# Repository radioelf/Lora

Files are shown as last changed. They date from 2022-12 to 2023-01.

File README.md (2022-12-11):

# Lora
Lora Radio
Molule E220 https://www.ebyte.com/en/product-view-news.html?id=1207

    Creative Commons License Disclaimer

  UNLESS OTHERWISE MUTUALLY AGREED TO BY THE PARTIES
  AND MAKES NO REPRESENTATIONS OR WARRANTIES OF ANY
  STATUTORY OR OTHERWISE, INCLUDING, WITHOUT LIMITAT
  FITNESS FOR A PARTICULAR PURPOSE, NONINFRINGEMENT,
  ACCURACY, OR THE PRESENCE OF ABSENCE OF ERRORS, WH
  DO NOT ALLOW THE EXCLUSION OF IMPLIED WARRANTIES,
  EXCEPT TO THE EXTENT REQUIRED BY APPLICABLE LAW, I
  ON ANY LEGAL THEORY FOR ANY SPECIAL, INCIDENTAL, C
  ARISING OUT OF THIS LICENSE OR THE USE OF THE WORK
  POSSIBILITY OF SUCH DAMAGES.

  http://creativecommons.org/licenses/by-sa/3.0/

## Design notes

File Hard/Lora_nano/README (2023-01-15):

PCB for Arduino Nano and module E220
Application: KiCad x86_64 on x86_64

Version: 7.0.0-rc1-unknown-00d77f624a~164~ubuntu22.04.1, release build

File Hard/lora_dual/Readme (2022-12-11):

Dual PCB for E220 PIC12F675 and ESP12F 
Application: KiCad

Version: 6.99.0-unknown-492e6548ff~162~ubuntu22.04.1, release build

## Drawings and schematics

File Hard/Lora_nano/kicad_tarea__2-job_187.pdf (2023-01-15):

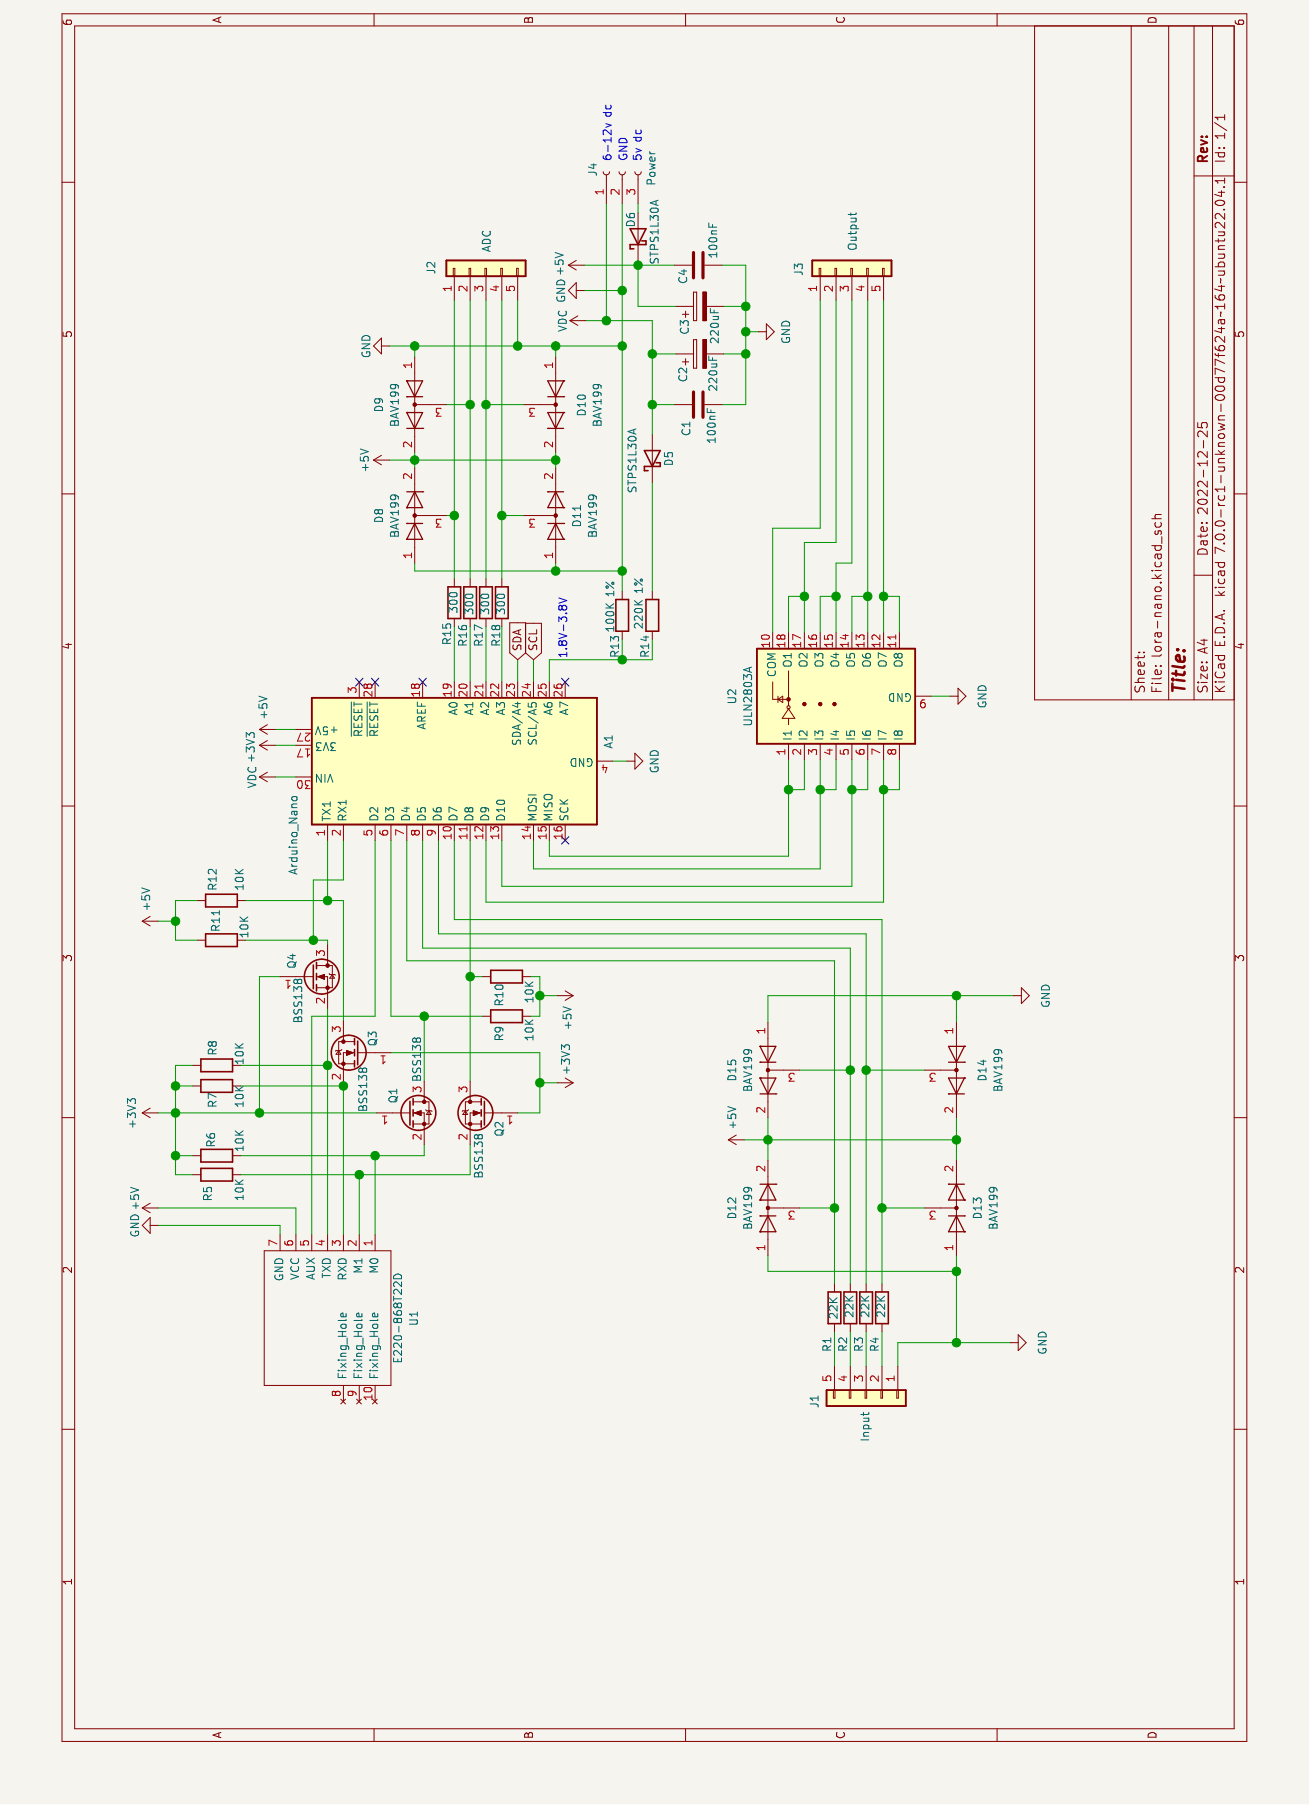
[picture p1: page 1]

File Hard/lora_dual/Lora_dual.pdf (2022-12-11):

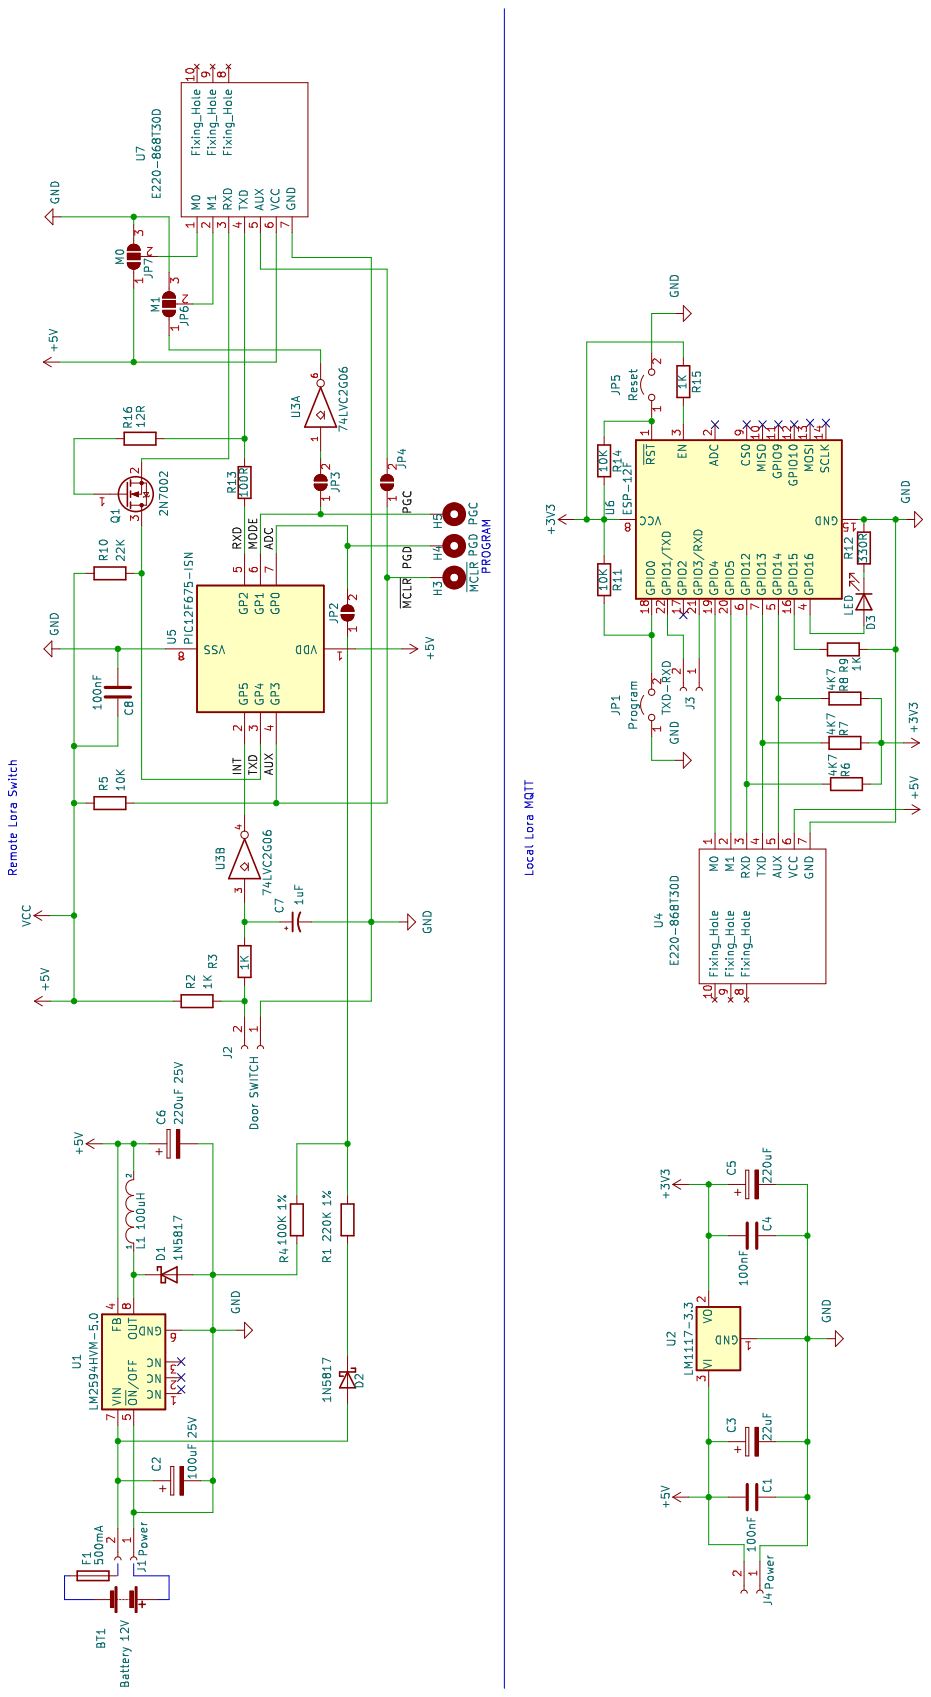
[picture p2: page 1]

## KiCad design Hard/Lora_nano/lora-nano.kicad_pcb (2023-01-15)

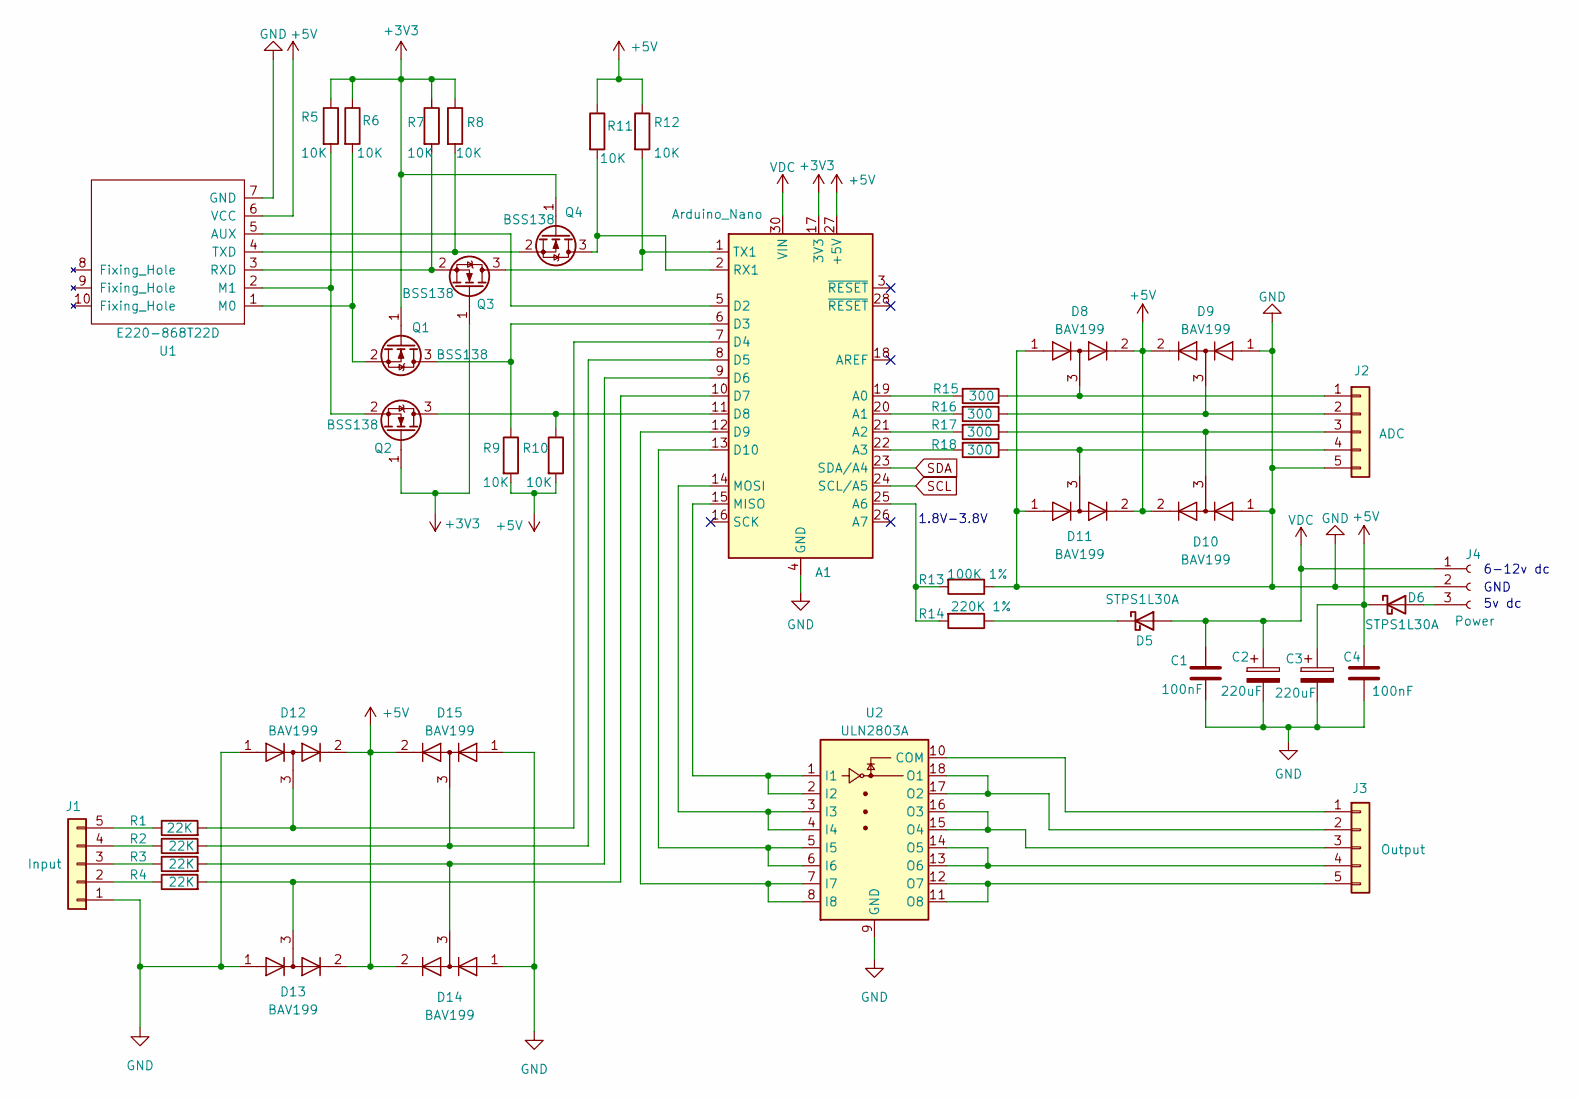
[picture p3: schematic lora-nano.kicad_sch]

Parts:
A1: Arduino_Nano
C1, C4: 100nF; C_0805_2012Metric
C2: 220uF; CP_Elec_8x6.2
C3: 220uF; CP_Elec_5x5.9
D5, D6: STPS1L30A; D_2010_5025Metric_Pad1.52x2.65mm_HandSolder
D8, D9, D10, D11, D12, D13, D14, D15: BAV199; SOT-23
J1: Input; PhoenixContact_MCV_1,5_5-G-3.5_1x05_P3.50mm_Vertical
J2: ADC; PhoenixContact_MCV_1,5_5-G-3.5_1x05_P3.50mm_Vertical
J3: Output; PhoenixContact_MCV_1,5_5-G-3.5_1x05_P3.50mm_Vertical
J4: Power; PhoenixContact_MCV_1,5_3-G-5.08_1x03_P5.08mm_Vertical
Q1, Q2, Q3, Q4: BSS138; SOT-23
R1, R2, R3, R4: 22K; R_0805_2012Metric
R5, R6, R7, R8, R9, R10, R11, R12: 10K; R_0805_2012Metric
R13: 100K 1%; R_Axial_DIN0204_L3.6mm_D1.6mm_P7.62mm_Horizontal
R14: 220K 1%; R_Axial_DIN0204_L3.6mm_D1.6mm_P7.62mm_Horizontal
R15, R16, R17, R18: 300; R_0805_2012Metric
U1: E220-868T22D; E32-xxxT20D-E220
U2: ULN2803A; SOIC-18W_7.5x11.6mm_P1.27mm

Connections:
+3V3: A1.17 (3V3), Q1.1 (G), Q2.1 (G), Q3.1 (G), Q4.1 (G), R5.1, R6.1, R7.1, R8.1
+5V: A1.27 (+5V), C3.1, C4.1, D6.1 (K), D8.2 (A), D9.2 (A), D10.2 (A), D11.2 (A), D12.2 (A), D13.2 (A), D14.2 (A), D15.2 (A), R9.2, R10.2, R11.1, R12.1, U1.6 (VCC); also elsewhere on the board
GND: A1.4 (GND), A1.29 (GND), C1.2, C2.2, C3.2, C4.2, D8.1 (K), D9.1 (K), D10.1 (K), D11.1 (K), D12.1 (K), D13.1 (K), D14.1 (K), D15.1 (K), J1.1, J2.5, J4.2, R13.1, U1.7 (GND), U2.9 (GND); also elsewhere on the board
unnamed: A1.19 (A0), R15.2
unnamed: A1.20 (A1), R16.2
unnamed: A1.21 (A2), R17.2
unnamed: A1.22 (A3), R18.2
unnamed: A1.25 (A6), R13.2, R14.2
unnamed: A1.5 (D2), U1.5 (AUX)
unnamed: A1.6 (D3), Q1.3 (D), R9.1
unnamed: A1.7 (D4), D12.3 (K), R1.2
unnamed: A1.8 (D5), D15.3 (K), R2.2
unnamed: A1.9 (D6), D14.3 (K), R3.2
unnamed: A1.10 (D7), D13.3 (K), R4.2
unnamed: A1.11 (D8), Q2.3 (D), R10.1
unnamed: A1.12 (D9), U2.7 (I7), U2.8 (I8)
unnamed: A1.13 (D10), U2.5 (I5), U2.6 (I6)
unnamed: A1.15 (MISO), U2.1 (I1), U2.2 (I2)
unnamed: A1.14 (MOSI), U2.3 (I3), U2.4 (I4)
unnamed 19: A1.2 (RX1), Q4.3 (D), R11.2; also elsewhere on the board
unnamed 20: A1.1 (TX1), Q3.3 (D), R12.2; also elsewhere on the board
unnamed: D5.1 (K), R14.1
unnamed: D6.2 (A), J4.3
unnamed: D8.3 (K), J2.1, R15.1
unnamed: D9.3 (K), J2.2, R16.1
unnamed: D10.3 (K), J2.3, R17.1
unnamed: D11.3 (K), J2.4, R18.1
unnamed: J1.2, R4.1
unnamed: J1.3, R3.1
unnamed: J1.4, R2.1
unnamed: J1.5, R1.1
unnamed: J3.1, U2.10 (COM)
unnamed: J3.2, U2.17 (O2), U2.18 (O1)
unnamed: J3.3, U2.15 (O4), U2.16 (O3)
unnamed: J3.4, U2.13 (O6), U2.14 (O5)
unnamed: J3.5, U2.11 (O8), U2.12 (O7)
unnamed: Q1.2 (S), R6.2, U1.1 (M0)
unnamed: Q2.2 (S), R5.2, U1.2 (M1)
unnamed: Q3.2 (S), R7.2, U1.3 (RXD)
unnamed: Q4.2 (S), R8.2, U1.4 (TXD)
SCL: A1.24 (SCL/A5); also elsewhere on the board
SDA: A1.23 (SDA/A4); also elsewhere on the board
VDC: A1.30 (VIN), C1.1, C2.1, D5.2 (A), J4.1

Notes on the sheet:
1.8V-3.8V
6-12v dc
5v dc
GND

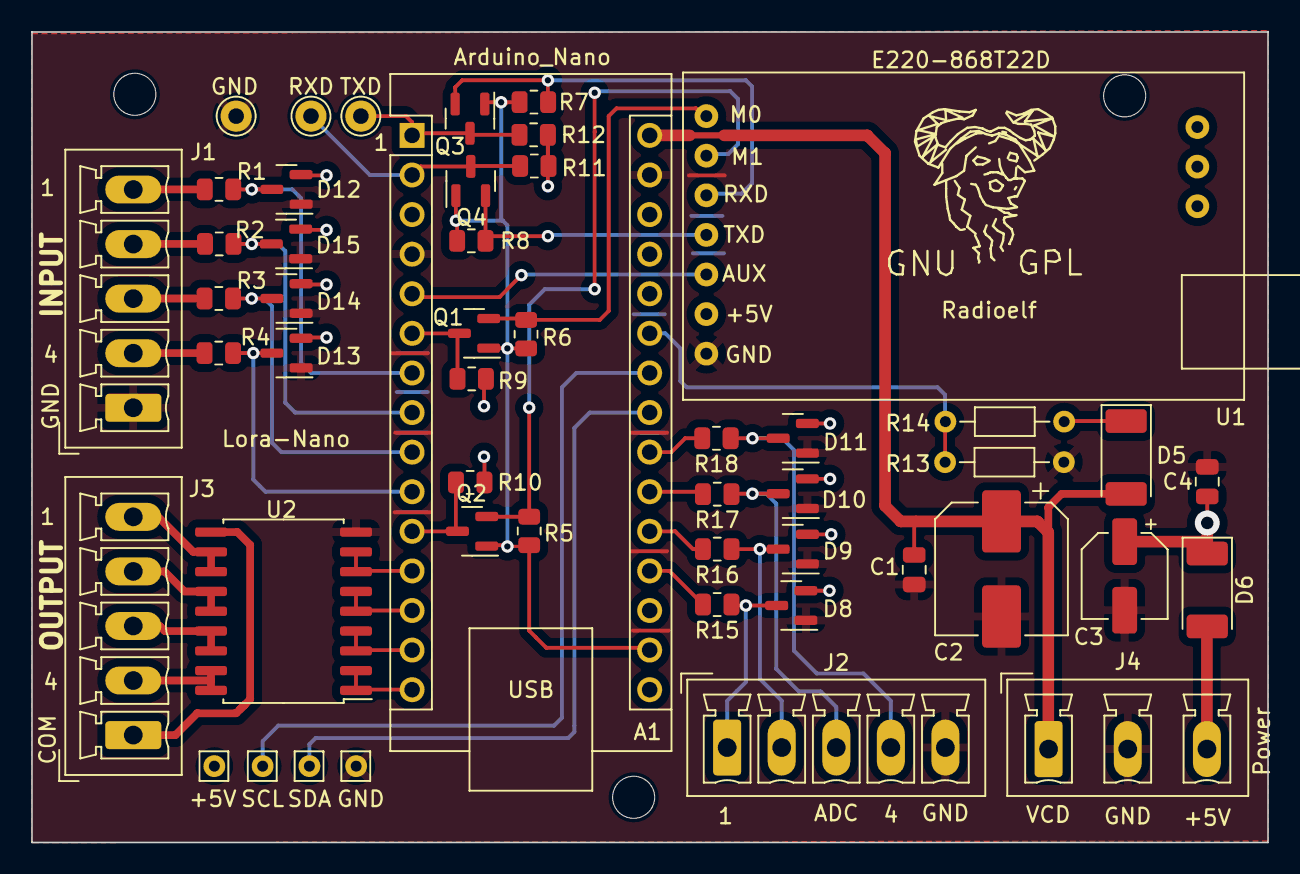
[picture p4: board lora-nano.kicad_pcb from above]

Board: 2 copper layers, 79.3 x 52.0 mm, 50 parts (0 on the bottom side), 43 nets.

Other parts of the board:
+5V: Pin_D0.7mm_L6.5mm_W1.8mm_FlatFork
GND: Pin_D1.0mm_L10.0mm
GND#2: Pin_D0.7mm_L6.5mm_W1.8mm_FlatFork
RXD: Pin_D1.0mm_L10.0mm
SCL: Pin_D0.7mm_L6.5mm_W1.8mm_FlatFork
SDA: Pin_D0.7mm_L6.5mm_W1.8mm_FlatFork
TXD: Pin_D1.0mm_L10.0mm

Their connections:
+5V: +5V.1; also elsewhere on the board
GND: GND.1, GND#2.1; also elsewhere on the board
unnamed 19: RXD.1; also elsewhere on the board
unnamed 20: TXD.1; also elsewhere on the board
SCL: SCL.1; also elsewhere on the board
SDA: SDA.1; also elsewhere on the board

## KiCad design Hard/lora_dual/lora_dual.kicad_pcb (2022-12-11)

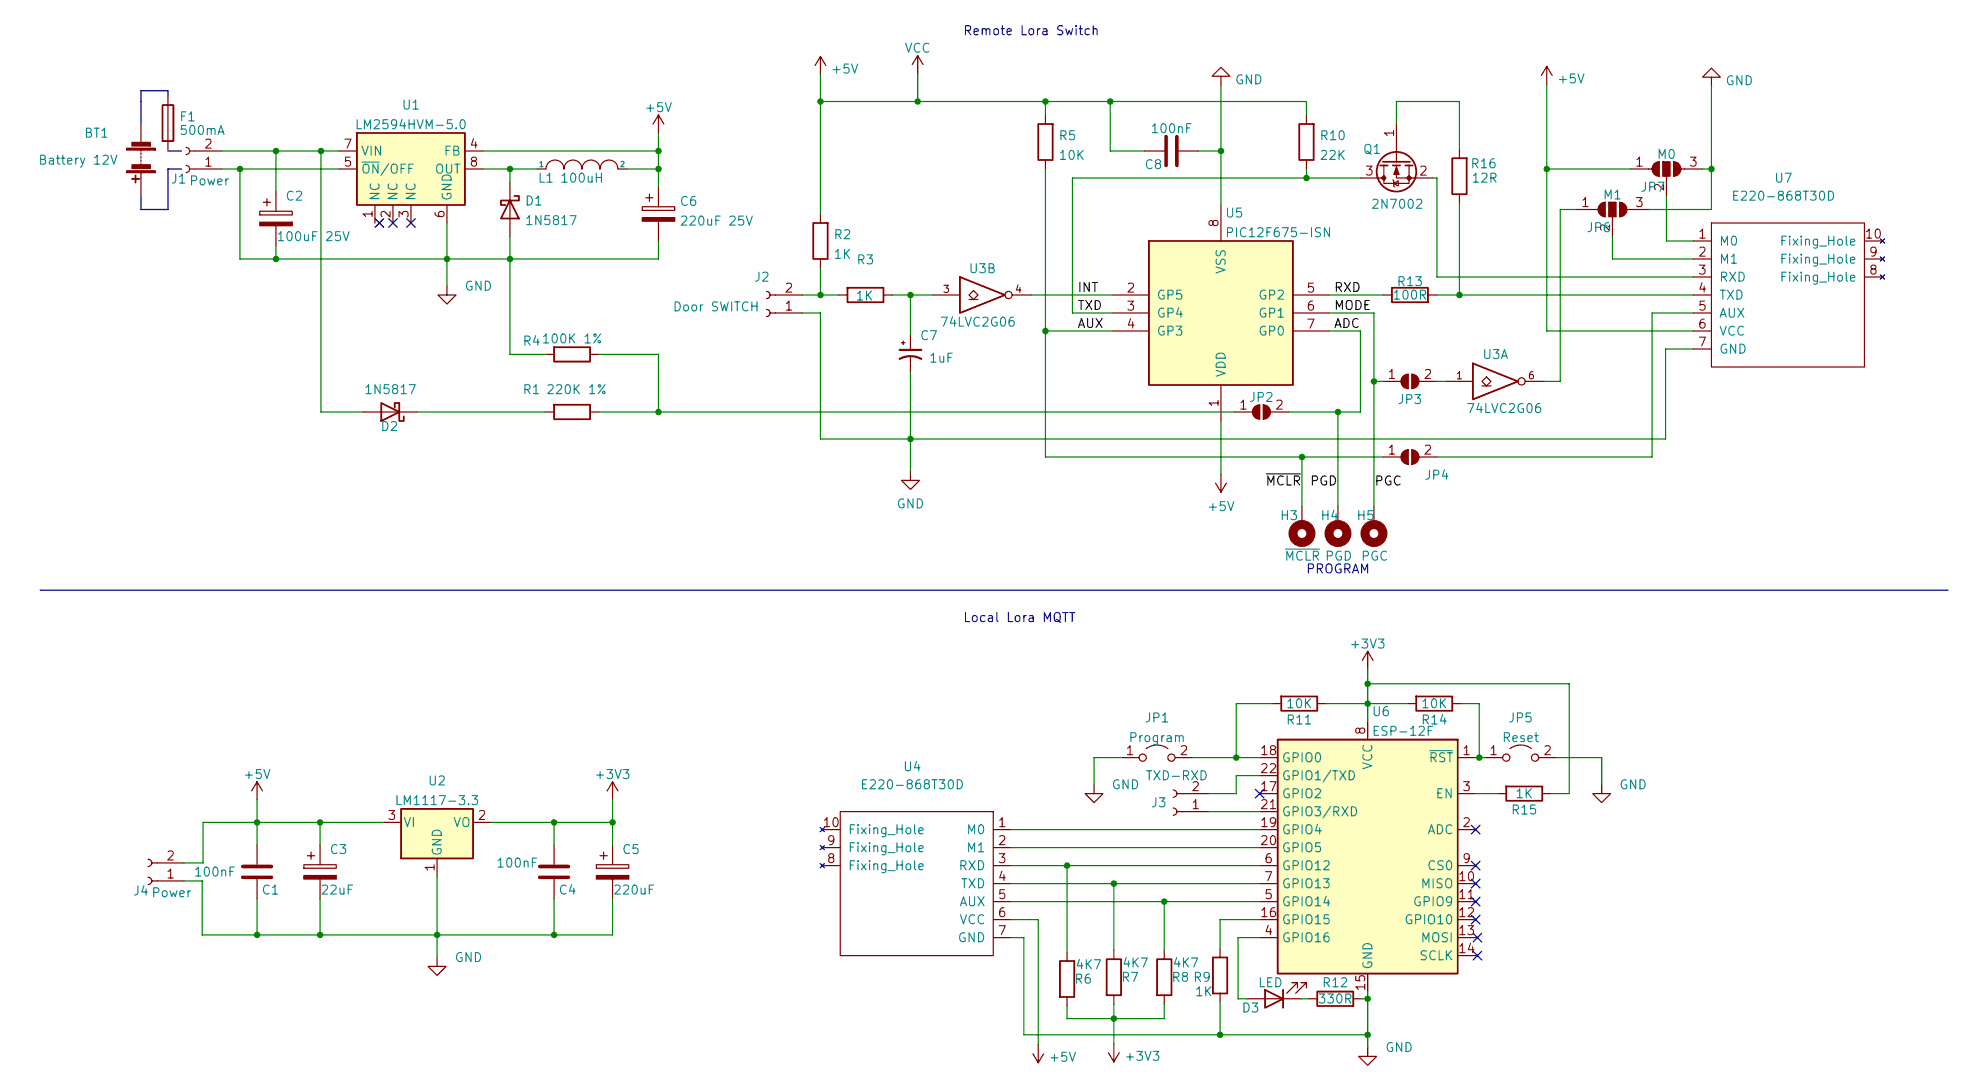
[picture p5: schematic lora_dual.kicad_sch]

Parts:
BT1: Battery 12V
C1, C4, C8: 100nF; C_0805_2012Metric
C2: 100uF 25V; CP_Elec_6.3x3
C3: 22uF; CP_Elec_4x5.8
C5: 220uF; CP_Elec_6.3x3
C6: 220uF 25V; CP_Elec_6.3x3
C7: 1uF; CP_Elec_3x5.3
D1, D2: 1N5817; D_DO-41_SOD81_P10.16mm_Horizontal
D3: LED; LED_0603_1608Metric
F1: 500mA
H3: ~{MCLR}; Pin_D0.7mm_L6.5mm_W1.8mm_FlatFork
H4: PGD; Pin_D0.7mm_L6.5mm_W1.8mm_FlatFork
H5: PGC; Pin_D0.7mm_L6.5mm_W1.8mm_FlatFork
J1, J4: Power; JWT_A3963_1x02_P3.96mm_Vertical
J2: Door SWITCH; JWT_A3963_1x02_P3.96mm_Vertical
J3: TXD-RXD; TestPoint_2Pads_Pitch2.54mm_Drill0.8mm
JP1: Program; TestPoint_2Pads_Pitch2.54mm_Drill0.8mm
JP2, JP4: Program; SolderJumper-2_P1.3mm_Open_RoundedPad1.0x1.5mm
JP3: PROGRAM; SolderJumper-2_P1.3mm_Open_RoundedPad1.0x1.5mm
JP5: Reset; TestPoint_2Pads_Pitch2.54mm_Drill0.8mm
JP6: M1; SolderJumper-3_P1.3mm_Open_RoundedPad1.0x1.5mm
JP7: M0; SolderJumper-3_P1.3mm_Open_RoundedPad1.0x1.5mm
L1: 100uH; L_Wuerth_WE-PDF
Q1: 2N7002; SOT-23
R1: 220K 1%; R_Axial_DIN0207_L6.3mm_D2.5mm_P10.16mm_Horizontal
R2, R3, R9, R15: 1K; R_0805_2012Metric
R4: 100K 1%; R_Axial_DIN0207_L6.3mm_D2.5mm_P10.16mm_Horizontal
R5, R11, R14: 10K; R_0805_2012Metric
R6, R7, R8: 4K7; R_0805_2012Metric
R10: 22K; R_0805_2012Metric
R12: 330R; R_0805_2012Metric
R13: 100R; R_0805_2012Metric
R16: 12R; R_0805_2012Metric
U1: LM2594HVM-5.0; SOIC-8_3.9x4.9mm_P1.27mm
U2: LM1117-3.3; SOT-223-3_TabPin2
U3: 74LVC2G06; SOT-23-6
U4, U7: E220-868T30D; E220-xxxTxxD
U5: PIC12F675-ISN; SOIC-8_3.9x4.9mm_P1.27mm
U6: ESP-12F; ESP-12E

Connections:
+3V3: C4.2, C5.1, R6.2, R7.2, R8.2, R11.1, R14.2, R15.1, U2.2 (VO), U6.8 (VCC)
+5V: C1.2, C3.1, C6.1, C8.1, J4.2, JP7.1 (A), L1.2, R2.2, R5.2, R10.2, U1.4 (FB), U2.3 (VI), U3.5 (VCC), U4.6 (VCC), U5.1 (VDD), U7.6 (VCC)
/ADC: H4.1, JP2.2 (B), U5.7 (GP0)
/AUX: H3.1, JP4.1 (A), R5.1, U5.4 (GP3)
/INT: U3.4, U5.2 (GP5)
/MODE: H5.1, JP3.1 (A), U5.6 (GP1)
/RXD: R13.1, U5.5 (GP2)
/TXD: Q1.3 (D), R10.1, U5.3 (GP4)
GND: C1.1, C2.2, C3.2, C4.1, C5.2, C6.2, C7.2, C8.2, D1.2 (A), J1.1, J2.1, J4.1, JP1.1 (A), JP5.2 (B), JP6.3 (B), JP7.3 (B), R4.2, R9.2, R12.2, U1.5 (~ON/OFF), U1.6 (GND), U2.1 (GND), U3.2 (GND), U4.7 (GND), U5.8 (VSS), U6.15 (GND), U7.7 (GND)
unnamed: C2.1, D2.2 (A), J1.2, U1.7 (VIN)
unnamed: C7.1, R3.1, U3.3
unnamed: D1.1 (K), L1.1, U1.8 (OUT)
unnamed: D2.1 (K), R1.2
unnamed: D3.1 (K), R12.1
unnamed: D3.2 (A), U6.4 (GPIO16)
unnamed: J2.2, R2.1, R3.2
unnamed: J3.1, U6.21 (GPIO3/RXD)
unnamed: J3.2, U6.22 (GPIO1/TXD)
unnamed: JP1.2 (B), R11.2, U6.18 (GPIO0)
unnamed: JP2.1 (A), R1.1, R4.1
unnamed: JP3.2 (B), U3.1
unnamed: JP4.2 (B), U7.5 (AUX)
unnamed: JP5.1 (A), R14.1, U6.1 (~RST)
unnamed: JP6.1 (A), U3.6
unnamed: JP6.2 (C), U7.2 (M1)
unnamed: JP7.2 (C), U7.1 (M0)
unnamed: Q1.1 (G), R16.2
unnamed: Q1.2 (S), U7.3 (RXD)
unnamed: R6.1, U4.3 (RXD), U6.6 (GPIO12)
unnamed: R7.1, U4.4 (TXD), U6.7 (GPIO13)
unnamed: R8.1, U4.5 (AUX), U6.5 (GPIO14)
unnamed: R9.1, U6.16 (GPIO15)
unnamed: R13.2, R16.1, U7.4 (TXD)
unnamed: R15.2, U6.3 (EN)
unnamed: U4.1 (M0), U6.19 (GPIO4)
unnamed: U4.2 (M1), U6.20 (GPIO5)

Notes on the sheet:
Local Lora MQTT
PROGRAM
Remote Lora Switch

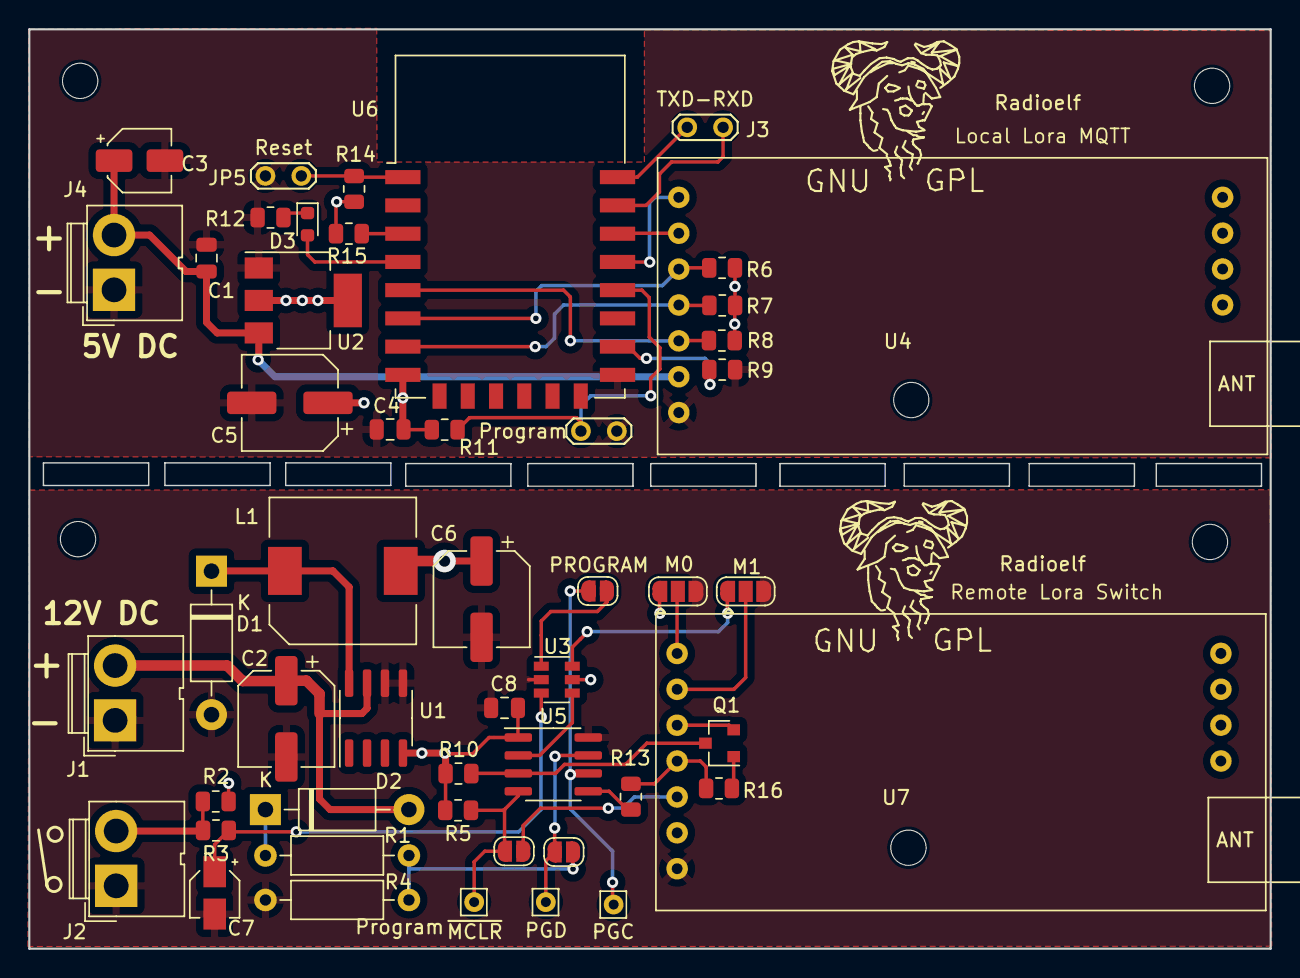
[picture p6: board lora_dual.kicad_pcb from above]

Board: 2 copper layers, 87.9 x 65.1 mm, 52 parts (0 on the bottom side), 36 nets.

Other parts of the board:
Radioelf: Symbol_GNU-Logo_SilkscreenTop
Radioelf#2: Symbol_GNU-Logo_SilkscreenTop

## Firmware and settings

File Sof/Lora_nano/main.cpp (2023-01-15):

/*************************************************************************************
Gestión de 4 entradas, 4 salidas y 4 entradas analógicas por un Arduino Nano y modulo Lora E220


V 0.0.2  15/1/23

 *     Creative Commons License Disclaimer
  UNLESS OTHERWISE MUTUALLY AGREED TO BY THE PARTIES
  AND MAKES NO REPRESENTATIONS OR WARRANTIES OF ANY
  STATUTORY OR OTHERWISE, INCLUDING, WITHOUT LIMITAT
  FITNESS FOR A PARTICULAR PURPOSE, NONINFRINGEMENT,
  ACCURACY, OR THE PRESENCE OF ABSENCE OF ERRORS, WH
  DO NOT ALLOW THE EXCLUSION OF IMPLIED WARRANTIES,
  EXCEPT TO THE EXTENT REQUIRED BY APPLICABLE LAW, I
  ON ANY LEGAL THEORY FOR ANY SPECIAL, INCIDENTAL, C
  ARISING OUT OF THIS LICENSE OR THE USE OF THE WORK
  POSSIBILITY OF SUCH DAMAGES.
  http://creativecommons.org/licenses/by-sa/3.0/

  Author: Radioelf  http://radioelf.blogspot.com.es/
 ************************************************************************************/
#include <Arduino.h>
#include <avr/sleep.h>
#include <avr/power.h>

#define E220Rxd 0                                                                     // pin nano RXD<--TXD E220
#define E220Txd 1                                                                     // pin nano TXD-->RXD E220
#define E220AUX 2
#define E220M0 3
#define INPUT1 4                                                                      // D4
#define INPUT2 5                                                                      // D5
#define INPUT3 6                                                                      // D6
#define INPUT4 7                                                                      // D7
#define E220M1 8
#define OUTPUT1 9
#define OUTPUT2 10
#define OUTPUT3 11
#define OUTPUT4 12
#define ADC1 A0
#define ADC2 A1
#define ADC3 A2
#define ADC4 A3
#define POWER A6

volatile uint8_t ISR = 0;

#include "e220.h"

void ReadAdc(void);
void DataJson(void);
uint8_t updateInput(void);

bool StatusD4 = 0, StatusD5 = 0, StatusD6 = 0, StatusD7 = 0;
String statusPower = "?", ReadADC1 = "?", ReadADC2 = "?", ReadADC3 = "?", ReadADC4 = "?";

/************************************************************************************/
// ISR para pines D4, D5, D6, y D7
/************************************************************************************/
ISR(PCINT2_vect)
{
  ISR = 1;
}
//////////////////////////////////////////////////////////////////////////////////////
void setup()
{
  pinMode(LED_BUILTIN, OUTPUT);
  pinMode(INPUT1, INPUT_PULLUP);
  pinMode(INPUT2, INPUT_PULLUP);
  pinMode(INPUT3, INPUT_PULLUP);
  pinMode(INPUT4, INPUT_PULLUP);
  pinMode(ADC1, INPUT);
  pinMode(ADC2, INPUT);
  pinMode(ADC3, INPUT);
  pinMode(ADC4, INPUT);
  pinMode(POWER, INPUT);
  pinMode(OUTPUT1, OUTPUT);
  pinMode(OUTPUT2, OUTPUT);
  pinMode(OUTPUT3, OUTPUT);
  pinMode(OUTPUT4, OUTPUT);
  digitalWrite(LED_BUILTIN, HIGH);

  Serial.begin(9600);
  delay(500);

  do
  {
    IniE220();                                                                        // inicializamos y modo WOR_RX
  }
  while (bitRead(errorE220, 7));
  // bits de habilitación de interrupción cambio estado del pines
  // Bit0 = 1 -> "PCIE0" enabeled (PCINT0 to PCINT7)
  // Bit1 = 1 -> "PCIE1" enabeled (PCINT8 to PCINT14)
  // Bit2 = 1 -> "PCIE2" enabeled D0-D7(PCINT16 to PCINT23)
  PCICR |= B00000100;
  // Bit4 = 1 -> "PCINT2" enabeled -> activará la interrupción de D4
  // Bit5 = 1 -> "PCINT2" enabeled -> activará la interrupción de D5
  // Bit6 = 1 -> "PCINT2" enabeled -> activará la interrupción de D6
  // Bit7 = 1 -> "PCINT2" enabeled -> activará la interrupción de D7
  PCMSK2 |= B11110000;
  cleanUARTBuffer();
  StatusD4 = digitalRead(INPUT1);
  StatusD5 = digitalRead(INPUT2);
  StatusD6 = digitalRead(INPUT3);
  StatusD7 = digitalRead(INPUT4);
  ReadAdc();
  digitalWrite(LED_BUILTIN, LOW);
}
//////////////////////////////////////////////////////////////////////////////////////
void sleepNow()
{
  digitalWrite(LED_BUILTIN, LOW);
  // Modos sleep:
  // SLEEP_MODE_IDLE - el modo de ahorro de energía más bajo, UART ON (unos 10mA)
  // SLEEP_MODE_ADC
  // SLEEP_MODE_PWR_SAVE
  // SLEEP_MODE_STANDBY
  // SLEEP_MODE_PWR_DOWN - el modo de ahorro de energía más alto (6 ciclos de reloj)
  set_sleep_mode(SLEEP_MODE_IDLE);

  sleep_enable(); 
// deshabilitamos periféricos NO usados en reposo
  power_adc_disable();
  power_spi_disable();
  power_timer0_disable();
  power_timer1_disable();
  power_timer2_disable();
  power_twi_disable();

  sleep_mode(); 

  sleep_disable(); 
// habilitamos todos los periféricos
  power_all_enable();
  
}
//////////////////////////////////////////////////////////////////////////////////////
void loop()
{ 
  // Gestión RX serial
  if (Serial.available())                                                             // tenemos datos serie?
  {
    digitalWrite(LED_BUILTIN, HIGH);
    if (RxE220() == false)                                                            // gestionamos trama RX y error en trama RX?
    {
      if (errorE220)                                                                  // error?
      {
        if (TxDataWOR())
        {
          Serial.print("RX_Error:" + String (errorE220));
          Serial.flush();
          delay(100);
          ModeE220(2);                                                                // WOR_RX
          errorE220 = 0;
        }
      }
      cleanUARTBuffer();
    }
    else                                                                              // OK RX-> Update o orden salidas
    {
      updateInput();
      if (TxDataWOR())
      {
        DataJson();
        delay(100);
        ModeE220(2);                                                                  // WOR_RX
      }
    }
  }
  // Gestión ISR
  if (ISR == 1)
  {
    digitalWrite(LED_BUILTIN, HIGH);
    delay(250);                                                                       // filtro rebotes
    if (updateInput() > 3)
    {
      if (TxDataWOR())
      {
        DataJson();
        delay(100);
        ModeE220(2);                                                                  // WOR_RX
      }
    }
    ISR = 0;
  }
  else
  {
    delay(1000);
    sleepNow();
  }
}
//////////////////////////////////////////////////////////////////////////////////////
uint8_t updateInput()
{
  ReadAdc();
  if (StatusD4 != digitalRead(INPUT1))
  {
    StatusD4 = digitalRead(INPUT1);
    ISR = 4;
  }
  if (StatusD5 != digitalRead(INPUT2))
  {
    StatusD5 = digitalRead(INPUT2);
    ISR = 5;
  }
  if (StatusD6 != digitalRead(INPUT3))
  {
    StatusD6 = digitalRead(INPUT3);
    ISR = 6;
  }
  if (StatusD7 != digitalRead(INPUT4))
  {
    StatusD7 = digitalRead(INPUT4);
    ISR = 7;
  }
  return ISR;
}
//////////////////////////////////////////////////////////////////////////////////////
float fmap(float x, float in_min, float in_max, float out_min, float out_max)
{
  return (x - in_min) * (out_max - out_min) / (in_max - in_min) + out_min;
}
//////////////////////////////////////////////////////////////////////////////////////
void ReadAdc()
{
  char str[4];                                                                        // string 3 posiciones + \0
  uint16_t value = analogRead(ADC1);
  Serial.println(value);
  float x = fmap(value, 0, 1023, 0.0, 5.0);                                           
  dtostrf(x, 1, 1, str);
  ReadADC1 = String(str);

  value = analogRead(ADC2);
  x = fmap(value, 0, 1023, 0.0, 5.0);
  dtostrf(x, 1, 1, str);
  ReadADC2 = String(str);
  
  value = analogRead(ADC3);
  x = fmap(value, 0, 1023, 0.0, 5.0);
  dtostrf(x, 1, 1, str);
  ReadADC3 = String(str);

  value = analogRead(ADC4);
  x = fmap(value, 0, 1023, 0.0, 5.0);
  dtostrf(x, 1, 1, str);
  ReadADC4 = String(str);

  value = analogRead(POWER);
  x = fmap(value, 0, 1023, 0.0, 5.0);  
  x = x * 3.23;                                                                       // corregimos tensión según divisor resistivo      
  if (x < 10)                                   
    dtostrf(x, 1, 1, str);
  else
    dtostrf(x, 2, 1, str);
  statusPower = String(str);
}
//////////////////////////////////////////////////////////////////////////////////////
// Máximo 200 Bytes (de 172 a 181bytes, máximo 180 + rssi)
//////////////////////////////////////////////////////////////////////////////////////
void DataJson()
{
  Serial.print("{\"E220\":[{\"In1\":\"" + String(StatusD4 ? "off" : "on") +
               "\",\"In2\":\"" + String(StatusD5 ? "off" : "on") +
               "\",\"In3\":\"" + String(StatusD6 ? "off" : "on") +
               "\",\"In4\":\"" + String(StatusD7 ? "off" : "on") +
               "\",\"Out1\":\"" + String(digitalRead(OUTPUT1) ? "on" : "off") +
               "\",\"Out2\":\"" + String(digitalRead(OUTPUT2) ? "on" : "off") +
               "\",\"Out3\":\"" + String(digitalRead(OUTPUT3) ? "on" : "off") +
               "\",\"Out4\":\"" + String(digitalRead(OUTPUT4) ? "on" : "off") +
               "\",\"ADC1\":\"" + ReadADC1 + "\",\"ADC2\":\"" + ReadADC2 +
               "\",\"ADC3\":\"" + ReadADC3 + "\",\"ADC4\":\"" + ReadADC4 +
               "\",\"Power\":\"" + statusPower + "\"}]}");
  Serial.flush();
}

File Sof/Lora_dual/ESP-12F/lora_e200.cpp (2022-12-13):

/*
ESP8266<---->E220(lora)--->MQTT-->Home Assistant

    Creative Commons License Disclaimer

  UNLESS OTHERWISE MUTUALLY AGREED TO BY THE PARTIES
  AND MAKES NO REPRESENTATIONS OR WARRANTIES OF ANY
  STATUTORY OR OTHERWISE, INCLUDING, WITHOUT LIMITAT
  FITNESS FOR A PARTICULAR PURPOSE, NONINFRINGEMENT,
  ACCURACY, OR THE PRESENCE OF ABSENCE OF ERRORS, WH
  DO NOT ALLOW THE EXCLUSION OF IMPLIED WARRANTIES,
  EXCEPT TO THE EXTENT REQUIRED BY APPLICABLE LAW, I
  ON ANY LEGAL THEORY FOR ANY SPECIAL, INCIDENTAL, C
  ARISING OUT OF THIS LICENSE OR THE USE OF THE WORK
  POSSIBILITY OF SUCH DAMAGES.

  http://creativecommons.org/licenses/by-sa/3.0/

  Author: Radioelf  http://radioelf.blogspot.com.es/
*/
#include <Arduino.h>
#include <ESP8266WiFi.h>
#include <ESP8266HTTPClient.h> // https://github.com/esp8266/Arduino/tree/master/libraries/ESP8266HTTPClient
#include <ESP8266WebServer.h>
#include <PubSubClient.h>

//#define DebugSerial 1

#include "ESP8266_OTA.h"

// ESP8266 RX GPIO13<-- TX E220, ESP8266 TX GPIO12--> RX E220, M0 ->GPIO4, M1 ->GPIO5, AUX->GPIO14
// pin led estado (gpio16)
#define LedPin 16

// Configuración red WiFi
const char *ssid = "xxxxx";
const char *password = "xxxxxx";
//const char *ssid = "yyyyyy";
//const char *password = "yyyyyyy";
//  configuración IP estática
IPAddress staticIP(192, 168, 0, xx);
IPAddress gateway(192, 168, 0, xx);
IPAddress dnServer(192, 168, 0, xx);
IPAddress subnet(255, 255, 255, 0);
// Nombre del punto de acceso si falla la conexión a la red WiFi
#define nameAp "LoraEsp"
#define passAp "xxxxxxx"

// Uptime overflow
#define UPTIME_OVERFLOW 4294967295UL

const char *sofVersion = "0.1.3";
const String Compiler = String(__DATE__);                                             // Obtenemos la fecha de la compilación

bool APmode = false;
bool okMqtt = false;
bool locate = false;

// valor del error para mostrar en pantalla
uint8_t errorDisplay = 0;

// 4.5 minutos (<MQTT_KEEPALIVE)

HTTPClient http;
// servidor HTTP run
WiFiClient clientHttp;

String statusBatt = "?";
String statusDoor = "?";
uint8_t battRx = 0;
uint8_t rssiRx = 0;
uint16_t contMqtt = 359;
uint16_t updateE220 = 1520;
uint16_t TxUpdate = 0;
bool doorRx = false;
bool loraOKdata = false;
bool updateLora = false;

#include "mqtt.h"
#include "e220.h"
#include "http.h"

ADC_MODE(ADC_VCC)

void getUptime();
void espReset();

//////////////////////////////////////////////////////////////////////////////////////
// Configuración
//////////////////////////////////////////////////////////////////////////////////////
void setup()
{
  // configuramos GPIOs
  pinMode(LedPin, OUTPUT);
  digitalWrite(LedPin, LOW);

  delay(250);
#if DebugSerial
  Serial.begin(115200);
  delay(500);
  debugPrintln(String(F("\n\n<-------\n\n")));
  // 1=normal boot, 4=watchdog, 2=reset pin, 3=software reset
  debugPrintln(String(F("SYSTEM: Reinicio por: ")) + String(ESP.getResetInfo()));
#else
  pinMode(LED_BUILTIN, OUTPUT);
  digitalWrite(LED_BUILTIN, LOW);
#endif
#if DebugSerial == 1
  debugPrintln(String(F("SYSTEM: ID ESP: ")) + String(ESP.getChipId()));
  debugPrintln(String(F("SYSTEM: CPU frecuencia: ")) + String(ESP.getCpuFreqMHz()) + "MHz");
  debugPrintln(String(F("SYSTEM: Versión Core: ")) + String(ESP.getCoreVersion()));
  debugPrintln(String(F("SYSTEM: Versión SDK: ")) + String(ESP.getSdkVersion()));
  debugPrintln(String(F("SYSTEM: Versión: ")) + String(sofVersion));
  debugPrintln(String(F("SYSTEM: Compilado: ")) + Compiler);
#endif

  // Tamaño máximo de paquete MQTT
  client.setBufferSize(1024);
  client.setKeepAlive(300);
  // Después de reiniciar aún se podría conserva la conexión antigua
  WiFi.disconnect();
  // No se guardar SSID y contraseña
  WiFi.persistent(false);
  // Reconectar si se pierde la conexión
  WiFi.setAutoReconnect(true);
  // Intentamos conectarnos a la red WIFI y luego conectarse al servidor MQTT
  reConnect();
  InitServer();
  if (InitOTA())
  {
#if DebugSerial
    debugPrintln(F("[OTA] Inicializado"));
  }
  else
  {
    debugPrintln(F("[OTA] ERROR!!"));
#endif
  }
  if (IniE220())
  {
    digitalWrite(LedPin, LOW);
    ModeE220(1);                                                                      // TX-RX WOD, pasamos a TX + código despertar
#if DebugSerial
    debugPrintln(F("[E220] Inicializado"));
  }
  else
  {
    debugPrintln(F("[E220] ERROR!!"));
#endif
  }
}
uint8_t timeAPmode = 0;
uint16_t contCicle = 0;
//************************************************************************************
// Principal
//************************************************************************************
void loop()
{
  // Reconectar si se perdió la conexión wifi o mqtt
  if (!client.connected() || WiFi.status() != 3)
  {
    reConnect();
  }

  if (updateLora)
  {
    TxE220("U");                                                                      // TX->despertar modulo remoto + 0x85 + RSSI
    updateLora = false;
    if (++TxUpdate > 1)
      bitSet(errorE220, 5);
  }
  if (RxE220())
  {
    locate = true;
    loraOKdata = true;
    publicMqtt();
    contCicle = 0;
    TxUpdate = 0;
    loraOKdata = false;
    locate = false;
    if (bitRead(errorE220, 5))
      bitClear(errorE220, 5);
    digitalWrite(LedPin, LOW);
  }

  delay(10);
  if (bitRead(errorE220, 7) && (contCicle % 20 == 0))
  {
      digitalWrite(LedPin, !digitalRead(LedPin));
  }
  // algo más de 40 segundos
  if (contCicle == 2000)
  {
      getUptime();
  }
  // algo más de 40 segundos
  if (++contCicle == 4000)
  {
      contCicle = 0;
      publicMqtt();
  }
  // Mantenemos activa la conexión MQTT
  client.loop();
  // escuchamos las conexiones http entrantes
  server.handleClient();
  ArduinoOTA.handle();
}
//////////////////////////////////////////////////////////////////////////////////////
// Reseteamos ESP
//////////////////////////////////////////////////////////////////////////////////////
void espReset()
{
#if DebugSerial
  debugPrintln(F("RESET ESP8266"));
#endif
  if (client.connected())
    client.disconnect();
  WiFi.disconnect();
  ESP.restart();
  delay(5000);
}
//////////////////////////////////////////////////////////////////////////////////////
// Gestión modo AP
//////////////////////////////////////////////////////////////////////////////////////
void wifiAP(bool OnOff)
{
  if (OnOff == false)
  {
    delay(5000);
    espReset();
  }
  WiFi.mode(WIFI_AP);
  // Canal RF 6, ISSD ON, 1 conexión
  while (!WiFi.softAP(nameAp, passAp, 6, 0, 1))
  {
    delay(100);
  }
  APmode = true;
#if DebugSerial
  debugPrintln(String(F("Configurado modo AP, nombre: ")) + String(nameAp) + " Pass: " + String(passAp));
  debugPrintln(String(F("IP: ")) + WiFi.softAPIP().toString());                       // Dirección para el AP
#endif
}
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

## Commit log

2023-01-15 Create Gerber\
2023-01-15 Create \Gerber
2023-01-28 Create sensor.yaml
    Para crear entidades de sensores en Home Assistant
2023-01-28 Create switch.yaml
    Para crear entidades de interruptores en Home Assistant
